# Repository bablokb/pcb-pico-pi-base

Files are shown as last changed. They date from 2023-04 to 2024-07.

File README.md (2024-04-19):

pcb-pico-pi-base
================

This projects provides two adapter-boards to run Pi-hats with a Pico.

The "pico-zero-base":

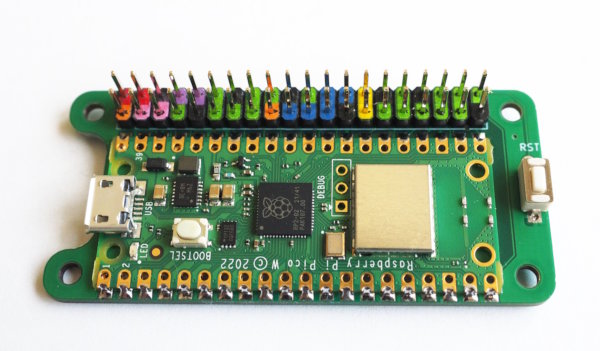
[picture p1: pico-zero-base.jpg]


and the "pico-pi-base":

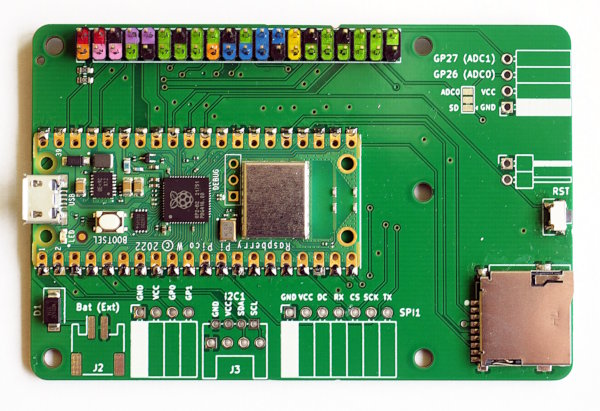
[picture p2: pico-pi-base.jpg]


The boards support (besides digital IO) I2C, I2S and SPI.

Supported Hats
--------------

The following hats were successfully tested:

  - Scroll pHat HD
  - Touch pHat
  - 4-Letter pHat
  - LED-Shim
  - Button-Shim
  - Pirate-Audio Speaker-Hat
  - Pirate-Audio Shim
  - Adafruit Speaker Bonnet
  - Display-Otron-Hat
  - InkyImpression  5.7"
  - Inky wHAT (black and white version)
  - Waveshare 4 inch RPi LCD (A)
  - I2C-Multiplexer-pHat

See the [examples page](examples/Readme.md) for details.

Hardware
--------

KiCad design-files are in `pico-zero-base.kicad` and in `pico-pi-base.kicad`
respectively. Ready to upload production files for JLCPCB are in `production_files`.

Except for I2C-pullups (and VSYS-diode on pico-pi-base) the adapter-boards
only map the pins of the Pico to pins of the Pi. The current versions
support I2C, SPI0, SPI1, I2S.

Schematic, layout and 3D-rendered images for pico-zero-base:

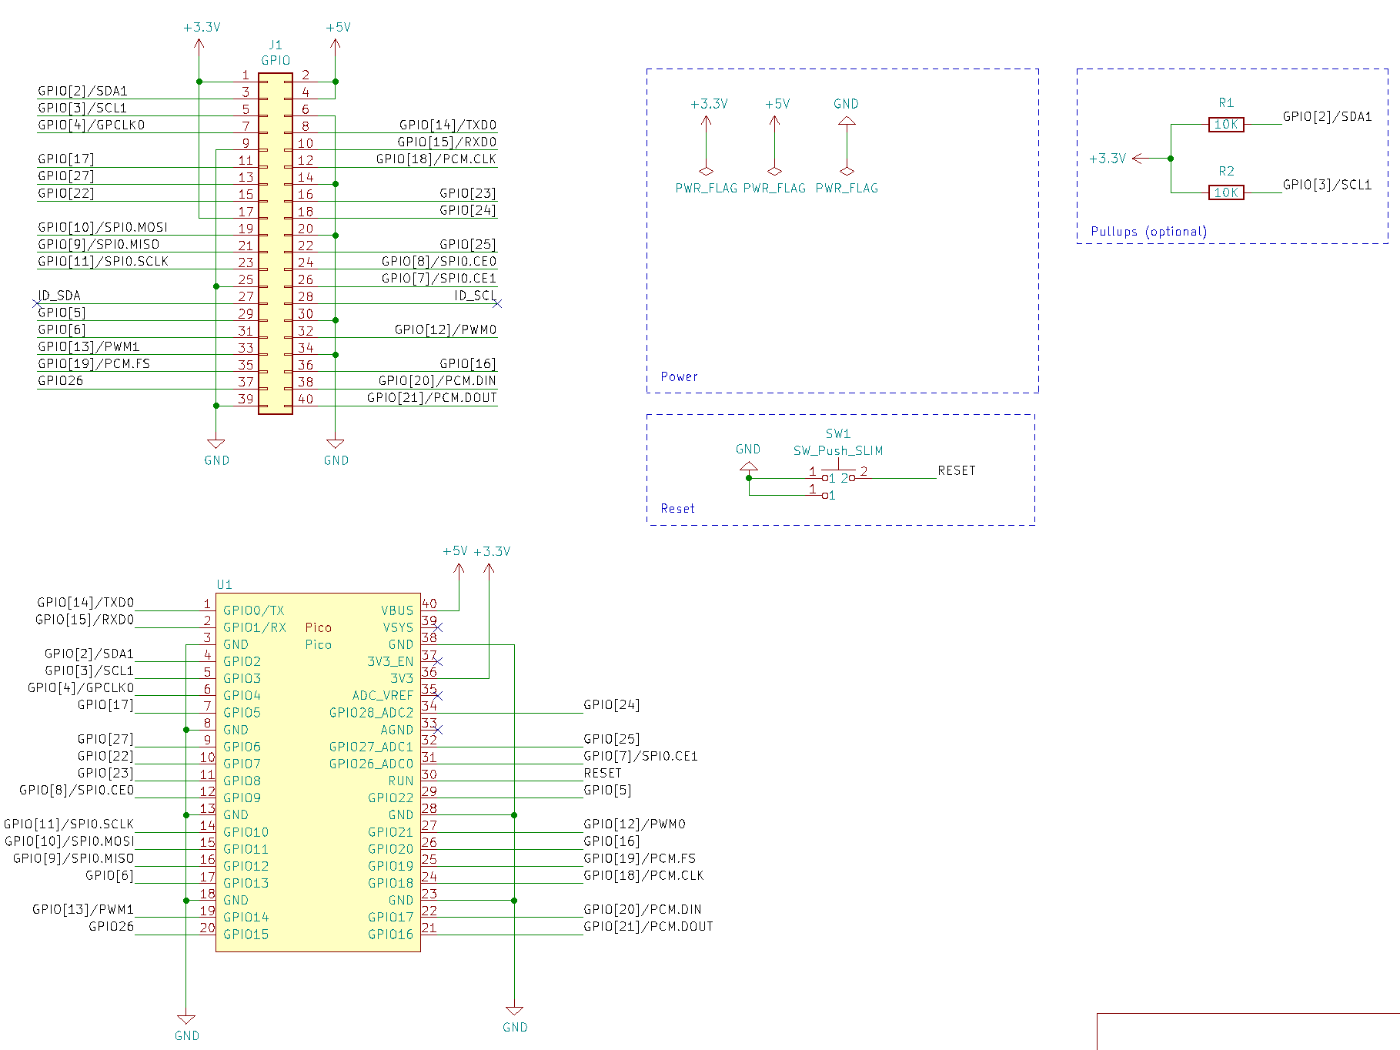
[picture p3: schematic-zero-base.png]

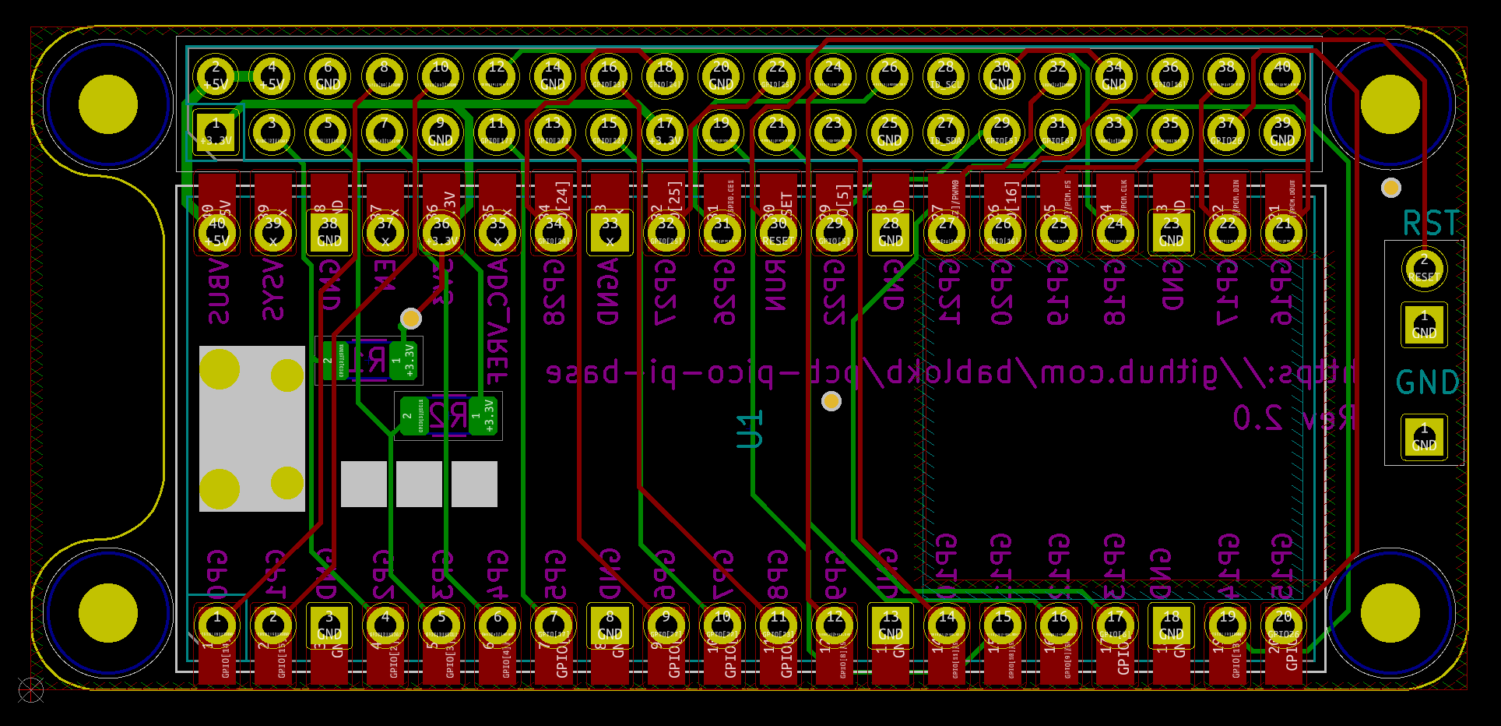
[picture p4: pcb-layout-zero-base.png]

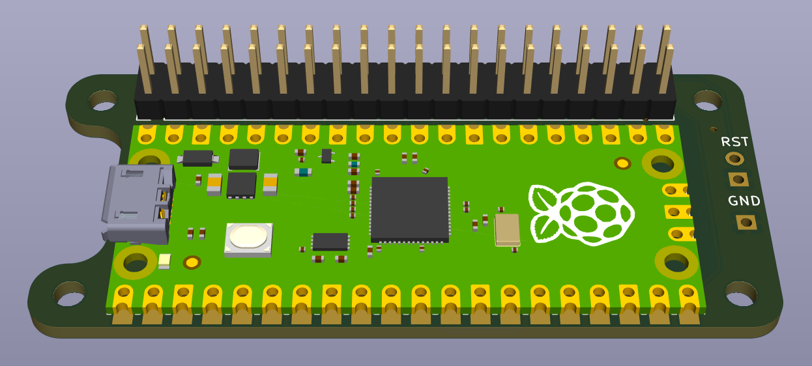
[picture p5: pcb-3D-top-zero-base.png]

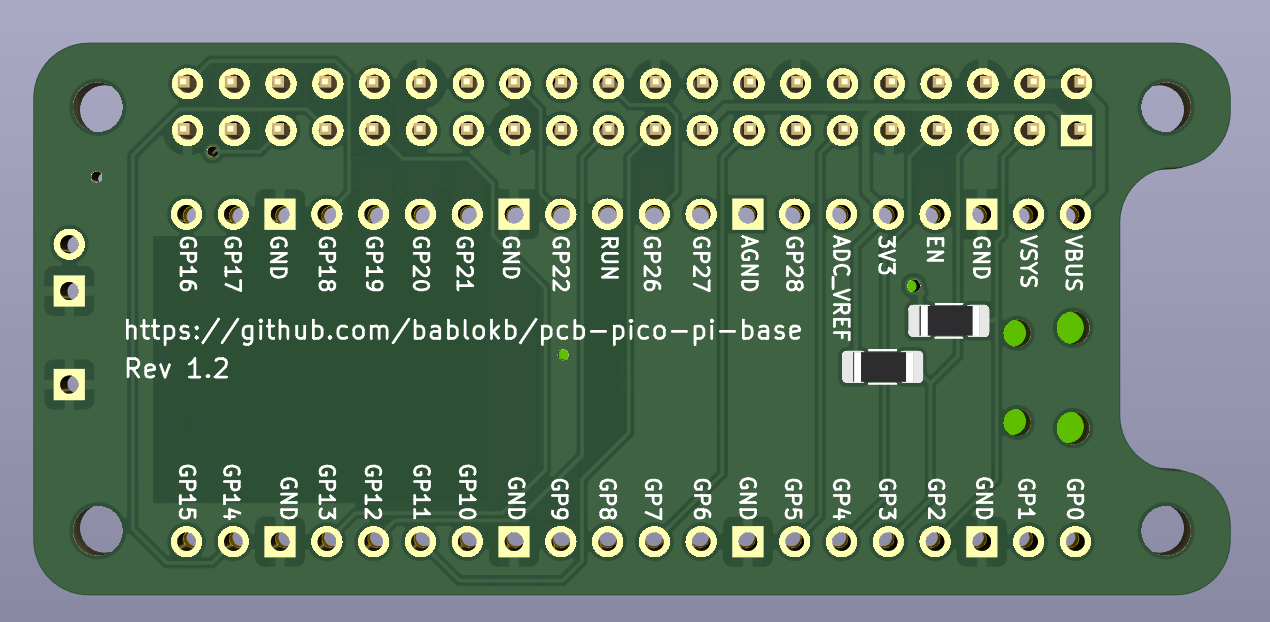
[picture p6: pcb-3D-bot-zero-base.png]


Schematic, layout and 3D-rendered images for pico-pi-base:

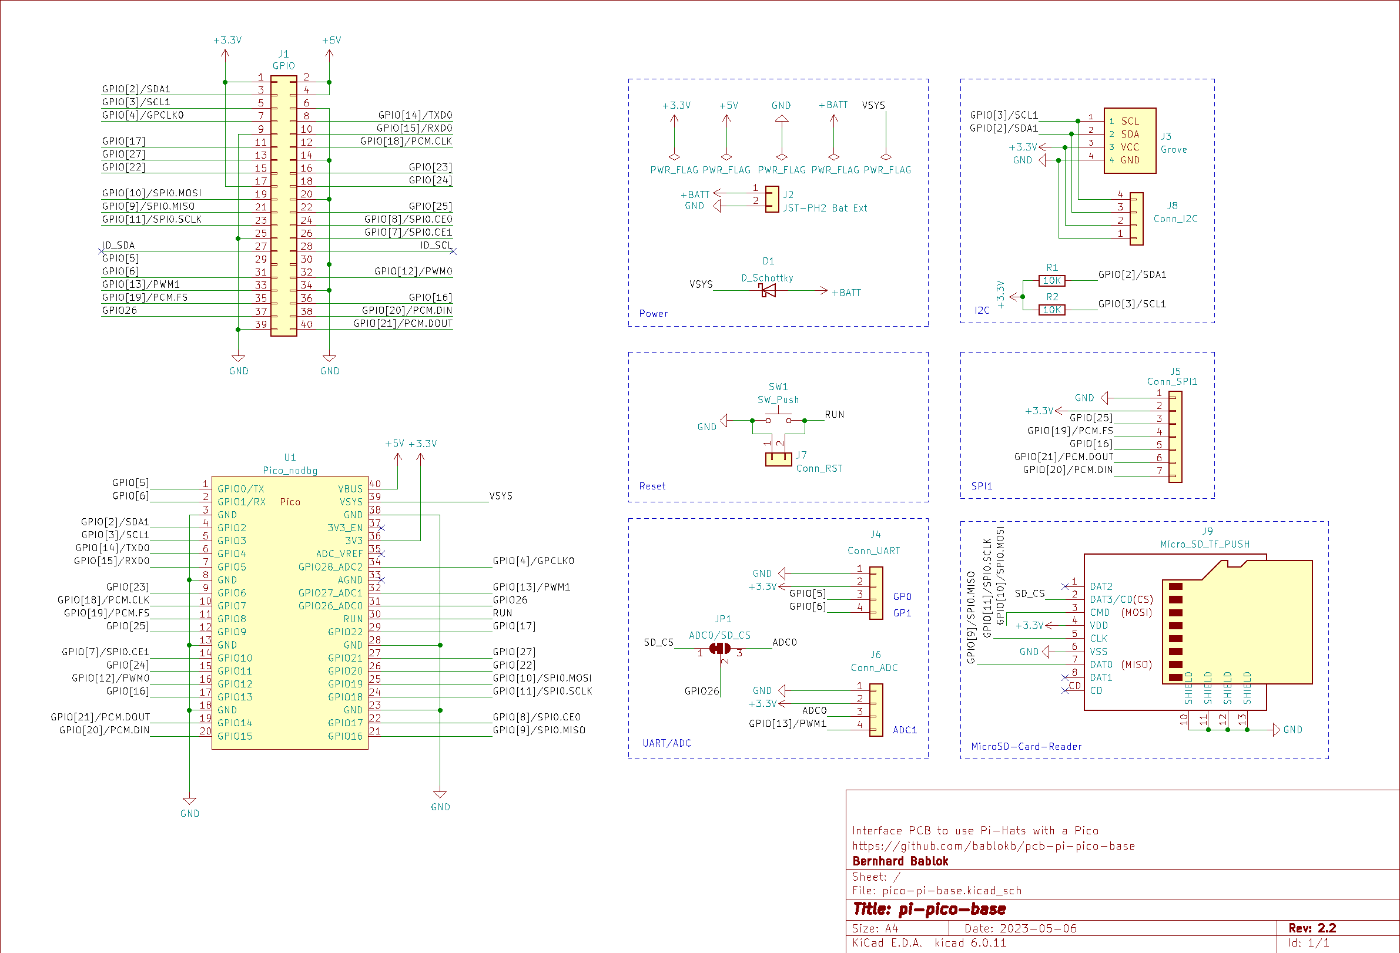
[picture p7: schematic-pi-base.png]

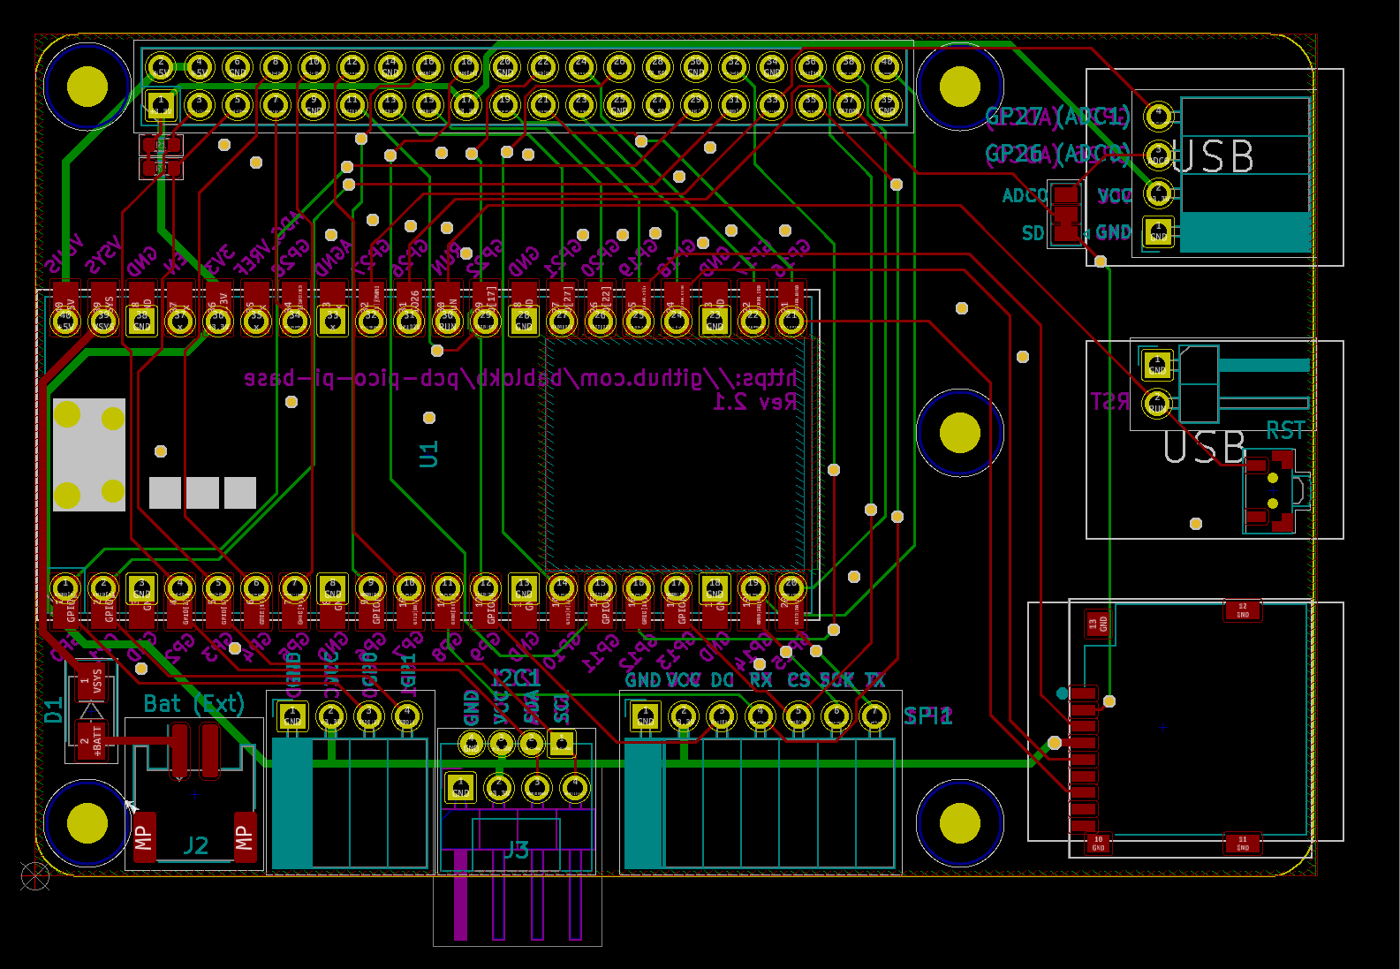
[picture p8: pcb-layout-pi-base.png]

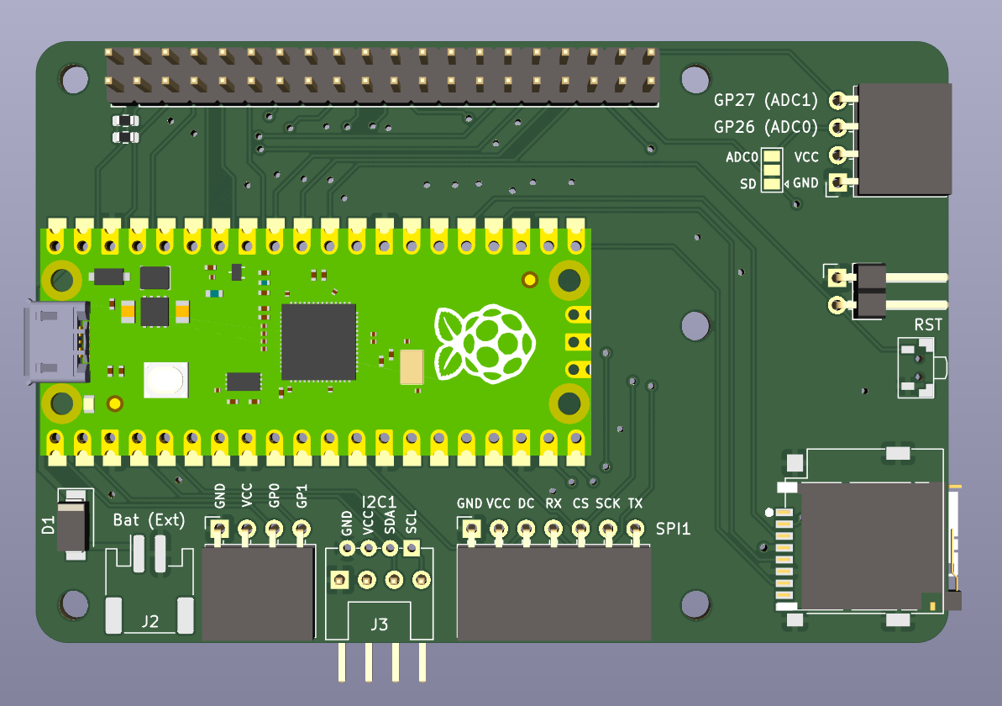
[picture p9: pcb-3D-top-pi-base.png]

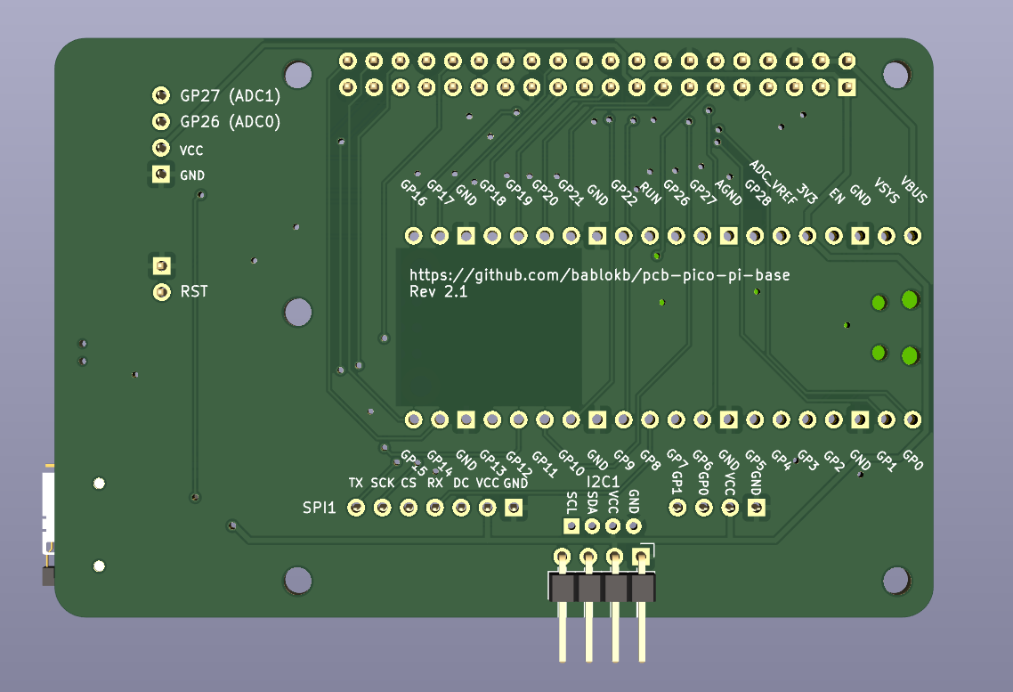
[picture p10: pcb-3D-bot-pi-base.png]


Software
--------

Since you cannot run Linux-software on the Pico, you need to check if there is a
Pico-driver available for your hats or adapt existing Pi drivers to the Pico. Since
many hats have python-drivers, this is not too difficult. Most hats only use
I2C and/or SPI anyhow.

In the directory `lib` you will find CircuitPython drivers for the supported
hats, unless there is a ready to use driver available.

The directory `examples` contains example programs.

The software currently assumes that you use special CircuitPython-builds
that do the pin mapping (see the directory `circuitpython`).
If not, you have to manually look up the [mapping](mapping.ods).

Porting to MicroPython from CircuitPython should be very simple, since
CircuitPython is only a fork of MicroPython and all the drivers use only
I2C, SPI and digital-IO.

License
-------

[![CC BY-SA 4.0][cc-by-sa-shield]][cc-by-sa]

This work is licensed under a
[Creative Commons Attribution-ShareAlike 4.0 International
License][cc-by-sa].

[][cc-by-sa]

[cc-by-sa]: http://creativecommons.org/licenses/by-sa/4.0/
[cc-by-sa-image]: https://licensebuttons.net/l/by-sa/4.0/88x31.png
[cc-by-sa-shield]:
https://img.shields.io/badge/License-CC%20BY--SA%204.0-lightgrey.svg

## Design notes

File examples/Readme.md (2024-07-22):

Examples
========

Some example programs for various hats. Check the `lib`-directory for
necessary (CircuitPython) drivers.

All the drivers assume that the mapping is done by the board-module.
E.g. the driver uses `board.GPIO24` and this is then mapped automatically
to the correct `board.GPxx`.

Some more examples are available here (for similar boards):
<https://github.com/dglaude/circuitpython_phat_on_pico>

Blinkt!
-------

This is a row of 8 APA102-LEDs with a connector. Simple and easy for nice
visual effects. It does not use I2C, but bit-banging with clock on GPIO24
and data on GPIO23. Porting was easy, replacing RPi.GPIO with digitalio.

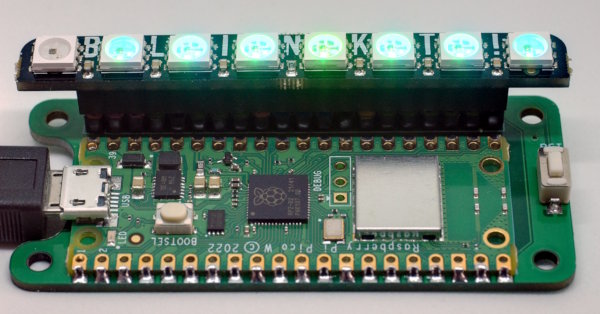
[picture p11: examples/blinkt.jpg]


Scroll pHat HD
--------------

Pimoroni's Scroll pHAT HD (now a retired product). Should also work
with the Scroll Hat Mini (<https://shop.pimoroni.com/products/scroll-hat-mini>).

A hat with 11x7 (monochrome) LEDs. The example is from
<http://github.com/adafruit/Adafruit_CircuitPython_IS31FL3731> and
uses the driver from that repo.

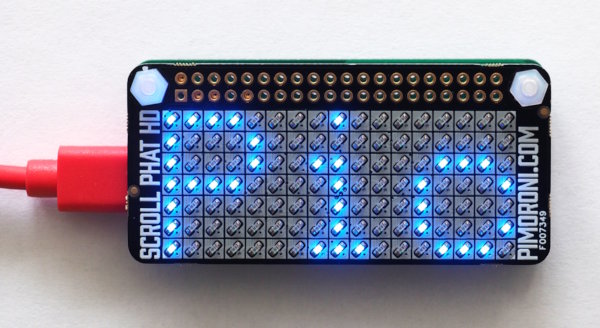
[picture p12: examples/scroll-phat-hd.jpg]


Touch pHat
----------

Pimoroni's Touch pHat <https://shop.pimoroni.com/products/touch-phat>.

The driver for the pHat and the CAP1166 chip were ported from the
Linux-version supplied by Pimoroni.

4-Letter pHat
-------------

A 4x14 segment display pHat <https://shop.pimoroni.com/products/four-letter-phat>.

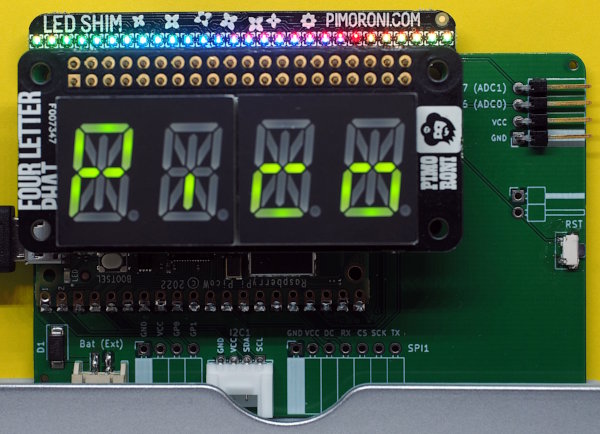
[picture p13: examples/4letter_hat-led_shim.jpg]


Works out of the box with <http://github.com/adafruit/Adafruit_CircuitPython_HT16K33>.

LED-Shim
--------

Also from Pimoroni <https://shop.pimoroni.com/products/led-shim>. You can see
it above the 4-letter pHat in the image above.

Same driver as the scroll pHat: <http://github.com/adafruit/Adafruit_CircuitPython_IS31FL3731>. The example is from that repo too.

Button-Shim
-----------

A small pcb with five buttons and a RGB-LED from Pimoroni:
<https://shop.pimoroni.com/products/button-shim>.

Pirate-Audio Speaker-Hat
------------------------

A hat from Pimoroni with a 240x240 display, four buttons, an audio DAC and
a small speaker (<https://shop.pimoroni.com/products/pirate-audio-mini-speaker>).

There are a few variants of this head available and all should work the same.

Rev1-boards only support the display and the buttons.
Rev2-boards also support audio.

All components are directly supported with standard CircuitPython drivers.

The hats have a major design flaw: they use the MISO-pin for the TFT-D/C,
so you cannot use SPI-devices together with this hat, at least as long as
you need MOSI. This really hurts, since this means you cannot read files
from the SD-card. And it is absolutely unnessary to use this pin, since
the Pi has so many other unused pins :-(

Audio DAC Shim
--------------

A solderless (more or less) shim with a 3.5mm line-out from Pimoroni
<https://shop.pimoroni.com/products/audio-dac-shim-line-out>.

Needs a Rev2-board. Audio-support for I2S is built into CircuitPython,
so no additional libs are necessary.

Adafruit Speaker-Bonnet
-----------------------

An audio hat with connectors for speakers, see
<https://www.adafruit.com/product/3346>.

This bonnet uses I2S and works without any additional libraries.
The example is from the guide
<https://learn.adafruit.com/adafruit-speaker-bonnet-for-raspberry-pi>. If you
compare the many pages of install instructions necessary to get this
working for a Pi you really love the simplicity of CircuitPython.

Adafruit LoRa-Bonnet
--------------------

A hat with a RFM9x-chip, three buttons and an I2C-OLED-display.
<https://www.adafruit.com/product/4074>.

The example is an adaption of the code in the guide
<https://learn.adafruit.com/multi-device-lora-temperature-network>.

Display-Otron-Hat
-----------------

From Pimoroni: <https://shop.pimoroni.com/products/display-o-tron-hat>.

The hat has a 3x16 character LCD with RGB backlight, six bar-graph
LEDs and six touch-buttons.

Fully supported, but the examples need some minor tweaks.

InkyImpression 4.0" and 5.7"
----------------------------

These 7-color e-ink displays are from Pimoroni:
<https://shop.pimoroni.com/products/inky-impression-5-7>

It is the same display as used in the InkyFrame 5.7", which has a Pico-W
attached. Main difference is that the latter also has a RTC and
some sophisticated power-management circuit.

The InkyImpression works out of the box with the SPD1656-driver from
Adafruit <http://github.com/adafruit/Adafruit_CircuitPython_SPD1656>.

Inky wHAT
---------

This is a 400x300 b&w e-ink display from Pimoroni (versions with an
additional color are also available, but are untested):
<https://shop.pimoroni.com/products/inky-what>

The driver is in `lib/what.py` and is a port of the (Linux-) Python-driver
from Pimoroni.

Inky pHAT
---------

This is a 250x122 b&w e-ink display from Pimoroni (versions with an
additional color are also available, but are untested):
<https://shop.pimoroni.com/products/inky-phat>

The driver is in `lib/phat.py` and is an adaption of the 
<https://github.com/adafruit/Adafruit_CircuitPython_SSD1608> driver
with input from the (Linux-) Python-driver of Pimoroni.

Waveshare 4-inch RPi LCD (A)
----------------------------

This is a 480x320 LCD-display with a 26-pin connector. It uses
the ILI4986-chip together with an XPT2046 for touch:
<https://www.waveshare.com/wiki/4inch_RPi_LCD_(A)>.

The display-driver needs a special hacked version of CircuitPython, the
patch is included in the directory `lib/ili9486_waveshare_4in`.

I2C-Multiplexer-pHat
--------------------

This 8-bus I2C-multiplexer pHat from independent maker 8086.net is based
on the TCA9548A and works with the TCA9548A-driver library from Adafruit
<https://github.com/adafruit/Adafruit_CircuitPython_TCA9548A>.

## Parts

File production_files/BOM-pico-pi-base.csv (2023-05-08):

Comment | Designator | Footprint | LCSC
D_Schottky | D1 | D_SMA | C2480
10K | R1,R2 | R_0603_1608Metric | C25804
Micro_SD_TF_PUSH | J9 | TF-Push | C393941

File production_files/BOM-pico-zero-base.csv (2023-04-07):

Comment | Designator | Footprint | LCSC
10K | R1,R2 | R_1206_3216Metric_Pad1.30x1.75mm_HandSolder | C17902

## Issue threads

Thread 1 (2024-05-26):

Not an issue: link to similar solution...

dglaude, 2024-05-26:
Hello,

Sorry not sure how to contact you... I found your article in Adafruit Playground.

When the Pico came out, I tried to find solution to reuse my HAT and pHAT collection on the pico... and use that with CircuitPython.

The best solution available at the time was Red Robotic Pico 2 Pi (that was available from Tindie): https://www.tomshardware.com/reviews/red-robotics-pico-2-pi-review-use-hats-with-raspberry-pi-pico ... maybe you can check this page to compare the mapping: https://www.hackster.io/news/the-pico-2-pi-adaptor-plate-proves-that-sometimes-it-s-the-simple-things-in-life-that-help-out-7f27e1de6208

I accumulated a few test in Circuit Python with various HAT: https://github.com/dglaude/circuitpython_phat_on_pico

I was in contact with the maker and helped make a new revision with SDA/SCL pull-up resistor. Indeed, your Raspberry Pi has that, and HAT / pHAT expect that, but on the Raspberry Pi Pico, because almost any pair of GPIO can be an I2C, there is none with the pull-up resistor.

At the time @arturo182 now owning Solder Party was working on a mapping and wanted to do a product that maybe never existed: https://www.hackster.io/news/the-zero-rp2040-is-an-rp2040-dev-board-that-tips-its-hat-to-the-former-zero-form-factor-8b71bf5a5deb

Now-a-day if someone want a PiZero like with with RP2040, I would suggest WaveShare RP2040-PiZero: https://www.waveshare.com/rp2040-pizero.htm ... I have two, I did not use them a lot, and especially not the unique aspect such as DVI/HDMI port or the USB Host (it require a OTG kind of cable).

Maybe you want to check those various attempt or product and compare your pin mapping or other technical decision they took.

Kind regards

David Glaude

bablokb, 2024-05-26:
Thanks for the links and infos. I indeed knew about the Robotic Pico 2 Pi hat, but it was neither available nor did I like the mappings. I will check your repo and if you like link from my examples page.

I also own the Waveshare board, but have not tested it. It is a very nice piece of engineering and the mapping seems ok except for I2S. The biggest drawback is the lack of WLAN. Another drawback is that many pins are used for other purposes and have added resistors, so you cannot just reuse them for your own purpose.

There is another adapter I recently discovered, available from The Pi Hut: https://thepihut.com/products/pico-to-pi-hat. Here also the mapping seems fine, but I also see no pullups.

dglaude, 2024-05-26:
Nice catch that PiHut version.

While writing my first message, I had in mind that I may have another I forgot to talk about... but that thing for pico to Pi mapping, I have "done it" (acquiring a few option) to map from Microbit (and especially the CLUE to Pi pinout) and also "done it" for Feather to Pi pinout too (also with one option from Arturo).

One thing I may have done is to import an alternate or overlay board.py that would map well know GPIO pin name to whatever is on the real board (like the pico). The goal was to have the example code work on different hardware without any modification.

One of the pin naming I wanted to have is the same that on CircuitPython running bare metal on Raspberry Pi Zero and/or on Blinka running on a Raspberry Pi (not sure if they are the same).

I think that the issue with WLAN is that it is kind of hard to have the Pico W chip and required licence outside of the Pico W... I don't think you can take a RP2040 and create a replica of the Pico W. So only adaptation board can have the Wifi and do that.

Anyway, good continuation with your project, I might get a copy, just like a might get the one from PiHut... just to have the whole collection. ;-)

bablokb, 2024-05-27:
I also tried to write a generic abstraction layer that makes the code work with all boards. It is too bad that you cannot monkey-patch board.py.

You can see my solution to the problem in the project https://github.com/bablokb/cp-departure-monitor. The hardware-abstraction-layer is loaded in `src/application.py`. This works with dynamic imports at runtime, loading a board-specific file and/or reading hardware-configuration from a settings-file. I am using this setup with all my (newer) projects and it works fine.

bablokb, 2024-06-03:
I added a link on the page `examples/Readme.md` to your repository.

Closed 2024-06-03.

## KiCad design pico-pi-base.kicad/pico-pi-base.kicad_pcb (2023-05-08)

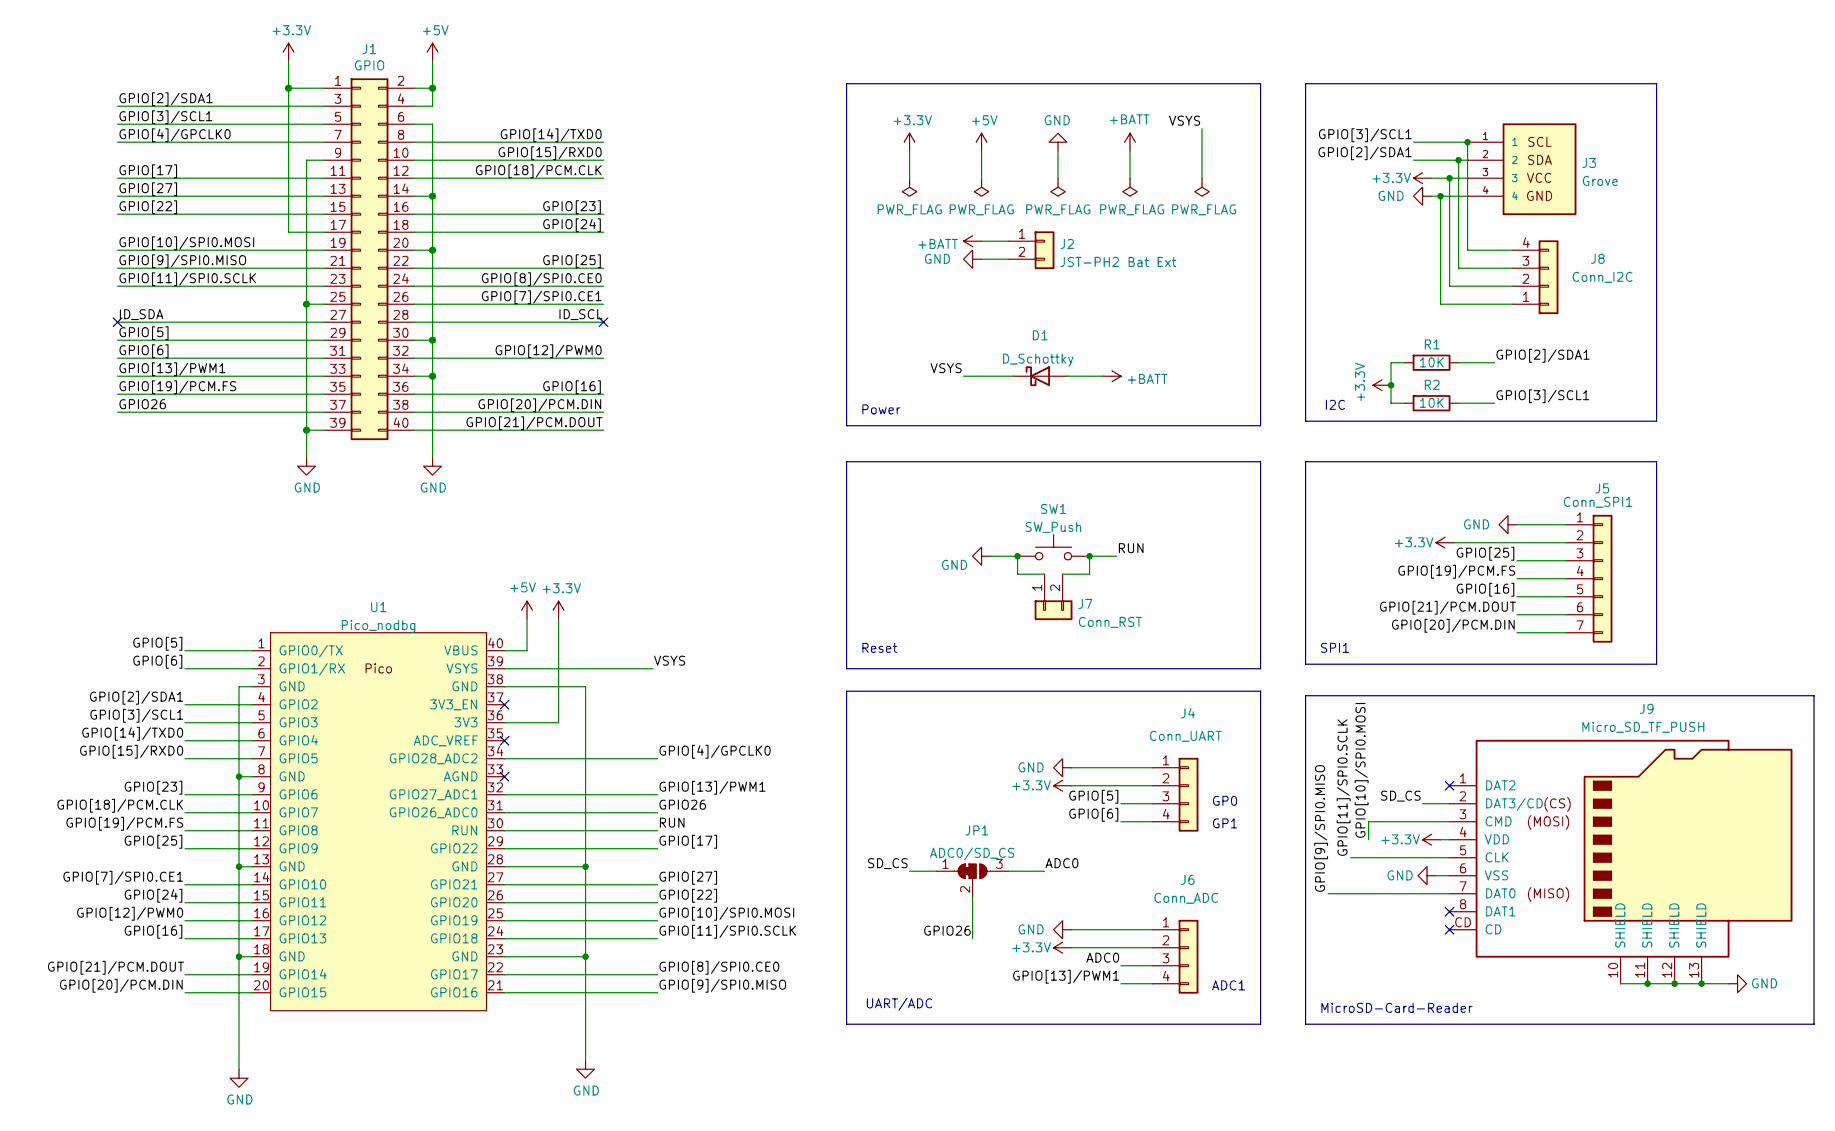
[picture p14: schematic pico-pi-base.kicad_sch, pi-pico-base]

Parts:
D1: D_Schottky; D_SMA; LCSC C2480
J1: GPIO; PinHeader_2x20_P2.54mm_Vertical
J2: JST-PH2 Bat Ext; JST_PH_S2B-PH-SM4-TB_1x02-1MP_P2.00mm_Horizontal
J3: Grove; grove_horizontal
J4: Conn_UART; PinSocket_1x04_P2.54mm_Horizontal
J5: Conn_SPI1; PinSocket_1x07_P2.54mm_Horizontal
J6: Conn_ADC; PinSocket_1x04_P2.54mm_Horizontal
J7: Conn_RST; PinHeader_1x02_P2.54mm_Horizontal
J8: Conn_I2C; PinHeader_1x04_P2.54mm_Horizontal
J9: Micro_SD_TF_PUSH; TF-Push; LCSC C393941
JP1: ADC0/SD_CS; SolderJumper-3_P1.3mm_Bridged12_Pad1.0x1.5mm
R1, R2: 10K; R_0603_1608Metric; LCSC C25804
SW1: SW_Push; Microtaster_Horizontal
U1: Pico_nodbg; RPi_Pico_SMD_TH_nodbg

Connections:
+3.3V: J1.1, J1.17, J3.3, J4.2, J5.2, J6.2, J8.2, J9.4 (VDD), R1.2, R2.2, U1.36 (3V3)
+5V: J1.2, J1.4, U1.40 (VBUS)
+BATT: D1.2 (A), J2.1
/ADC0: J6.3, JP1.3 (B)
/GPIO26: J1.37, JP1.2 (C), U1.31 (GPIO26_ADC0)
/GPIO[2]/SDA1: J1.3, J3.2, J8.3, R1.1, U1.4 (GPIO2)
/GPIO[3]/SCL1: J1.5, J3.1, J8.4, R2.1, U1.5 (GPIO3)
/GPIO[4]/GPCLK0: J1.7, U1.34 (GPIO28_ADC2)
/GPIO[5]: J1.29, J4.3, U1.1 (GPIO0/TX)
/GPIO[6]: J1.31, J4.4, U1.2 (GPIO1/RX)
/GPIO[7]/SPI0.CE1: J1.26, U1.14 (GPIO10)
/GPIO[8]/SPI0.CE0: J1.24, U1.22 (GPIO17)
/GPIO[9]/SPI0.MISO: J1.21, J9.7 (DAT0), U1.21 (GPIO16)
/GPIO[10]/SPI0.MOSI: J1.19, J9.3 (CMD), U1.25 (GPIO19)
/GPIO[11]/SPI0.SCLK: J1.23, J9.5 (CLK), U1.24 (GPIO18)
/GPIO[12]/PWM0: J1.32, U1.16 (GPIO12)
/GPIO[13]/PWM1: J1.33, J6.4, U1.32 (GPIO27_ADC1)
/GPIO[14]/TXD0: J1.8, U1.6 (GPIO4)
/GPIO[15]/RXD0: J1.10, U1.7 (GPIO5)
/GPIO[16]: J1.36, J5.5, U1.17 (GPIO13)
/GPIO[17]: J1.11, U1.29 (GPIO22)
/GPIO[18]/PCM.CLK: J1.12, U1.10 (GPIO7)
/GPIO[19]/PCM.FS: J1.35, J5.4, U1.11 (GPIO8)
/GPIO[20]/PCM.DIN: J1.38, J5.7, U1.20 (GPIO15)
/GPIO[21]/PCM.DOUT: J1.40, J5.6, U1.19 (GPIO14)
/GPIO[22]: J1.15, U1.26 (GPIO20)
/GPIO[23]: J1.16, U1.9 (GPIO6)
/GPIO[24]: J1.18, U1.15 (GPIO11)
/GPIO[25]: J1.22, J5.3, U1.12 (GPIO9)
/GPIO[27]: J1.13, U1.27 (GPIO21)
/ID_SCL: J1.28
/ID_SDA: J1.27
/RUN: J7.2, SW1.2, U1.30 (RUN)
/SD_CS: J9.2 (DAT3/CD), JP1.1 (A)
/VSYS: D1.1 (K), U1.39 (VSYS)
GND: J1.6, J1.9, J1.14, J1.20, J1.25, J1.30, J1.34, J1.39, J2.2, J3.4, J4.1, J5.1, J6.1, J7.1, J8.1, J9.6 (VSS), J9.10 (SHIELD), J9.11 (SHIELD), J9.12 (SHIELD), J9.13 (SHIELD), SW1.1, U1.3 (GND), U1.8 (GND), U1.13 (GND), U1.18 (GND), U1.23 (GND), U1.28 (GND), U1.38 (GND)

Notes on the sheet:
Reset
GP0
Power
GP1
MicroSD-Card-Reader
SPI1
UART/ADC
I2C
ADC1

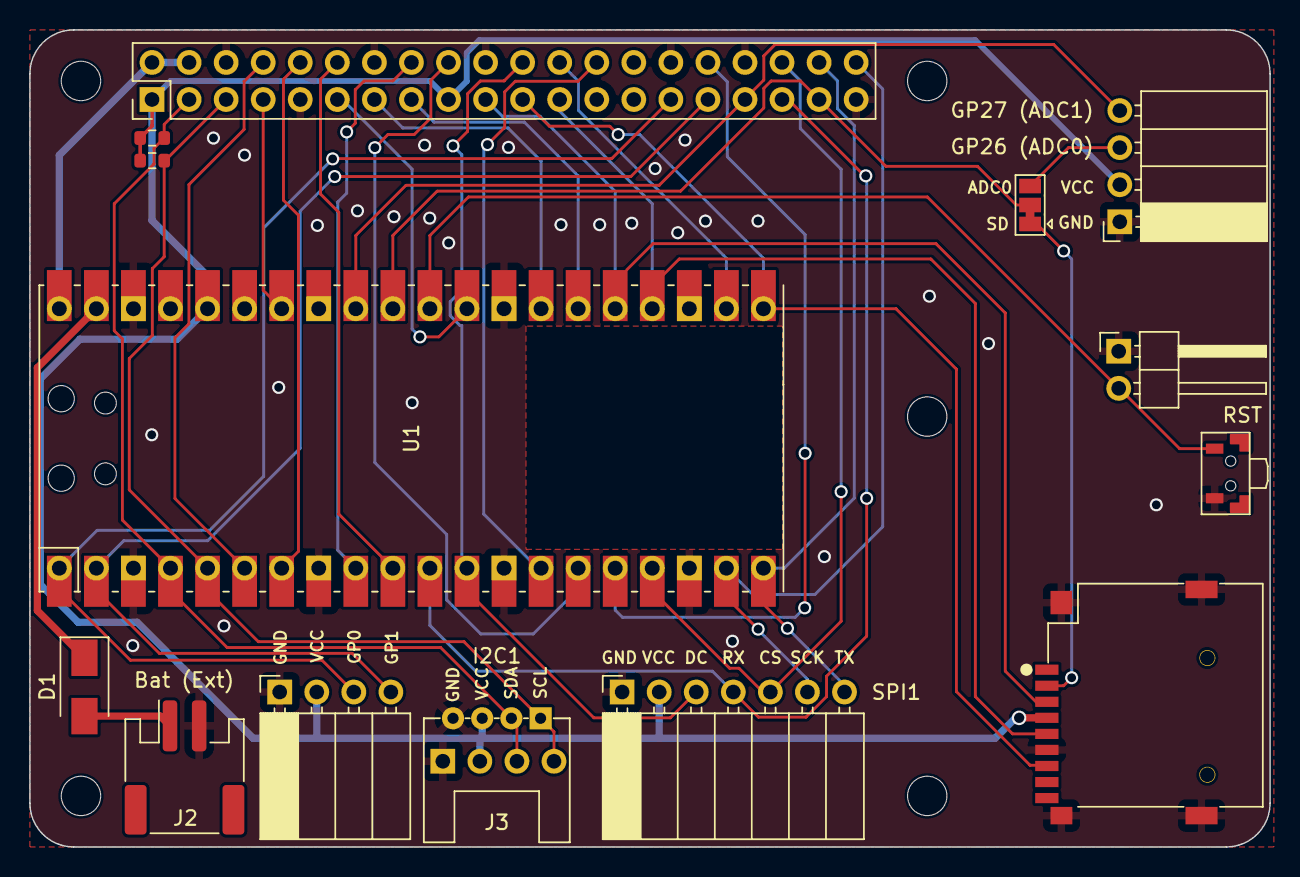
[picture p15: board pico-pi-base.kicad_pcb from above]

Board: 2 copper layers, 85.0 x 56.0 mm, 20 parts (1 on the bottom side), 34 nets.

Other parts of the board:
MH1, MH1#2, MH2, MH3, MH4: MountingHole_2.7mm_M2.5

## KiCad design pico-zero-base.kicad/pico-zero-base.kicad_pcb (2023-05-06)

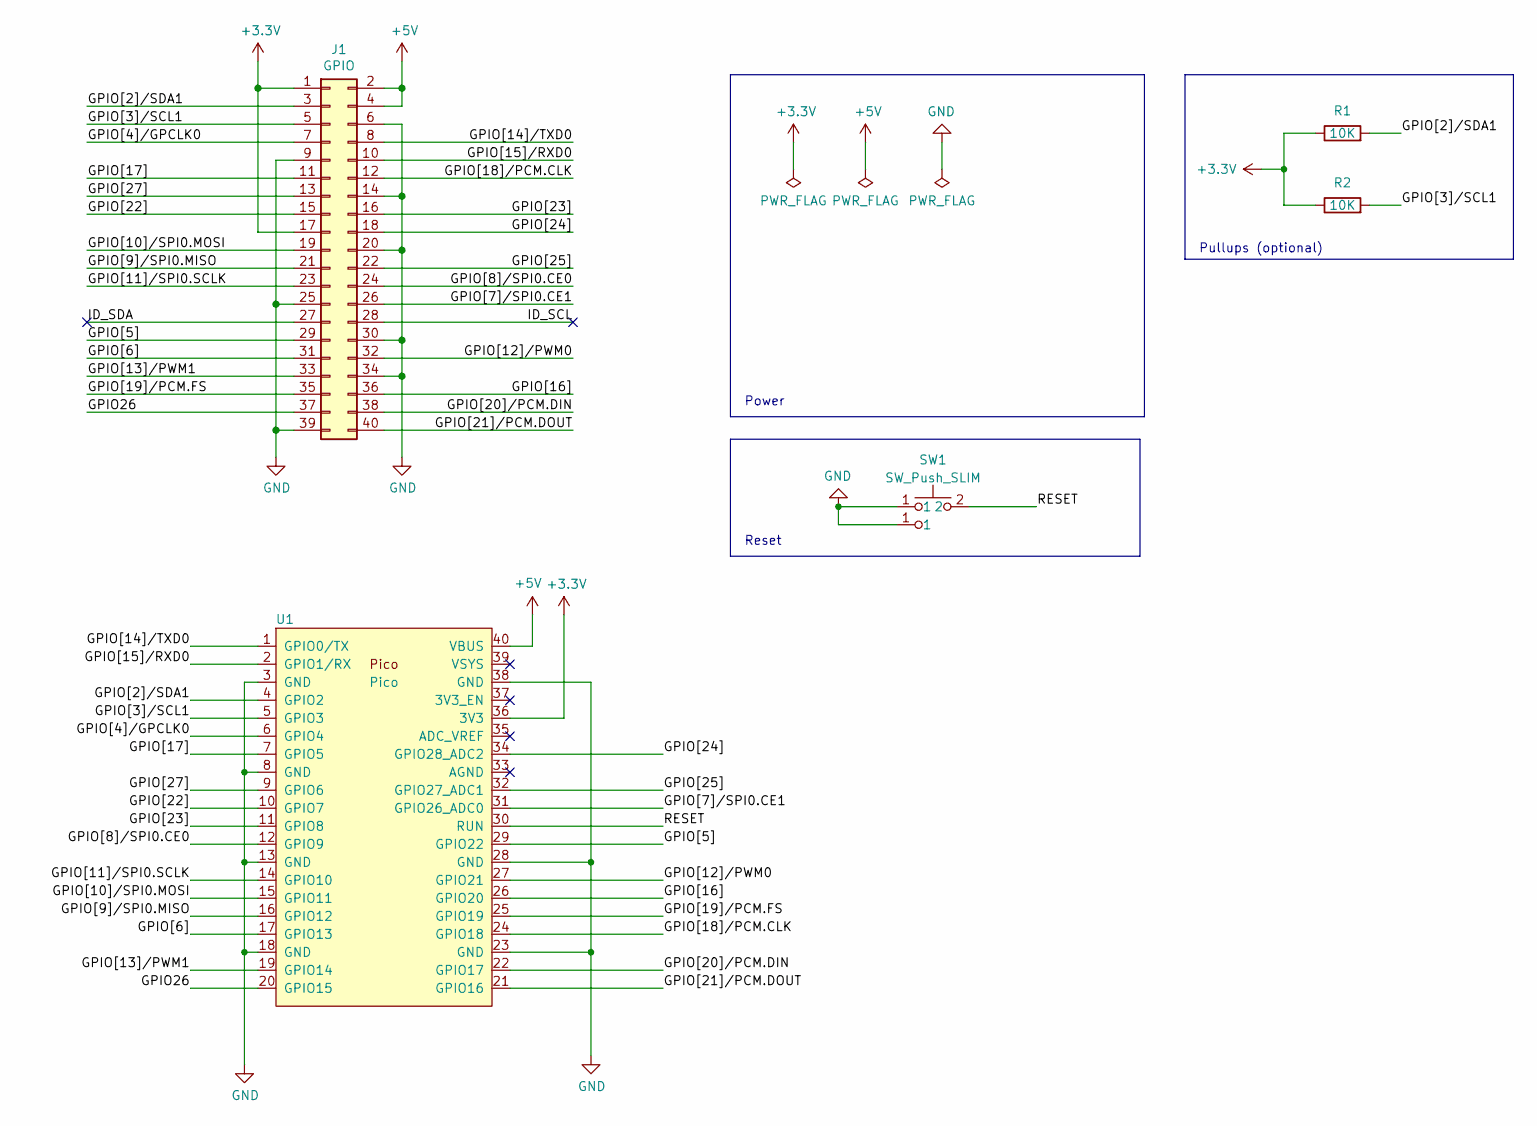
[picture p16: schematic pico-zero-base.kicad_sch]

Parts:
J1: GPIO; PinHeader_2x20_P2.54mm_Vertical
R1, R2: 10K; R_1206_3216Metric_Pad1.30x1.75mm_HandSolder; LCSC C17902
SW1: SW_Push_SLIM; SW_PUSH_SLIM_1x4
U1: Pico; RPi_Pico_SMD_TH_nodbg

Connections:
+3.3V: J1.1, J1.17, R1.1, R2.1, U1.36 (3V3)
+5V: J1.2, J1.4, U1.40 (VBUS)
/GPIO26: J1.37, U1.20 (GPIO15)
/GPIO[2]/SDA1: J1.3, R1.2, U1.4 (GPIO2)
/GPIO[3]/SCL1: J1.5, R2.2, U1.5 (GPIO3)
/GPIO[4]/GPCLK0: J1.7, U1.6 (GPIO4)
/GPIO[5]: J1.29, U1.29 (GPIO22)
/GPIO[6]: J1.31, U1.17 (GPIO13)
/GPIO[7]/SPI0.CE1: J1.26, U1.31 (GPIO26_ADC0)
/GPIO[8]/SPI0.CE0: J1.24, U1.12 (GPIO9)
/GPIO[9]/SPI0.MISO: J1.21, U1.16 (GPIO12)
/GPIO[10]/SPI0.MOSI: J1.19, U1.15 (GPIO11)
/GPIO[11]/SPI0.SCLK: J1.23, U1.14 (GPIO10)
/GPIO[12]/PWM0: J1.32, U1.27 (GPIO21)
/GPIO[13]/PWM1: J1.33, U1.19 (GPIO14)
/GPIO[14]/TXD0: J1.8, U1.1 (GPIO0/TX)
/GPIO[15]/RXD0: J1.10, U1.2 (GPIO1/RX)
/GPIO[16]: J1.36, U1.26 (GPIO20)
/GPIO[17]: J1.11, U1.7 (GPIO5)
/GPIO[18]/PCM.CLK: J1.12, U1.24 (GPIO18)
/GPIO[19]/PCM.FS: J1.35, U1.25 (GPIO19)
/GPIO[20]/PCM.DIN: J1.38, U1.22 (GPIO17)
/GPIO[21]/PCM.DOUT: J1.40, U1.21 (GPIO16)
/GPIO[22]: J1.15, U1.10 (GPIO7)
/GPIO[23]: J1.16, U1.11 (GPIO8)
/GPIO[24]: J1.18, U1.34 (GPIO28_ADC2)
/GPIO[25]: J1.22, U1.32 (GPIO27_ADC1)
/GPIO[27]: J1.13, U1.9 (GPIO6)
/ID_SCL: J1.28
/ID_SDA: J1.27
/RESET: SW1.2, U1.30 (RUN)
GND: J1.6, J1.9, J1.14, J1.20, J1.25, J1.30, J1.34, J1.39, SW1.1, U1.3 (GND), U1.8 (GND), U1.13 (GND), U1.18 (GND), U1.23 (GND), U1.28 (GND), U1.38 (GND)

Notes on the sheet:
Pullups (optional)
Power
Reset

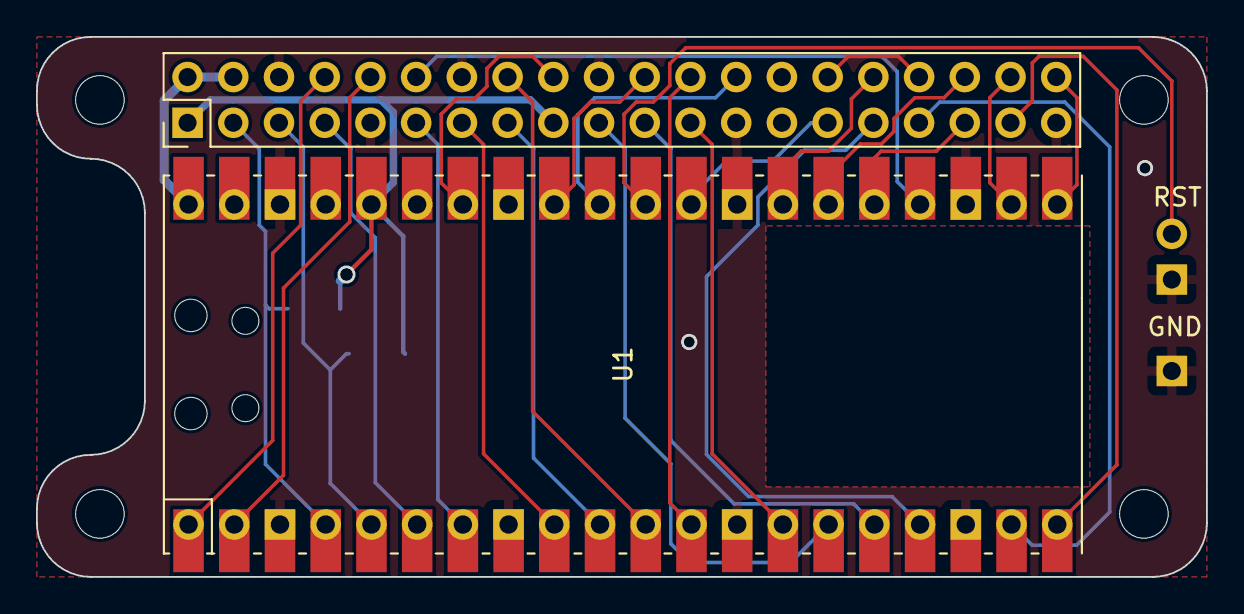
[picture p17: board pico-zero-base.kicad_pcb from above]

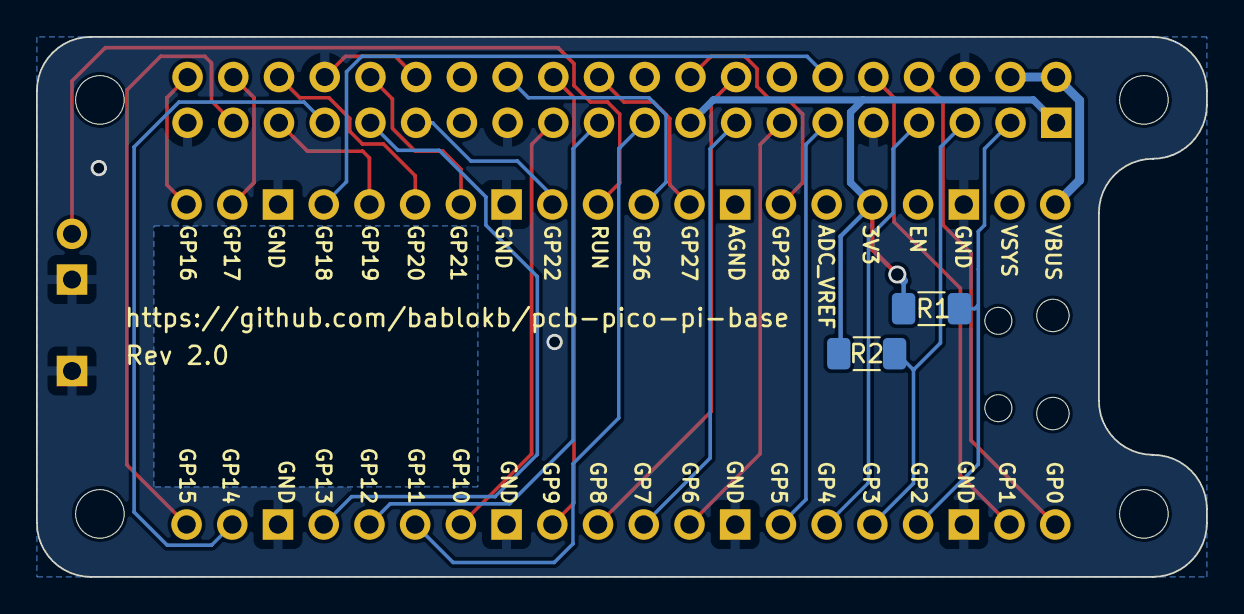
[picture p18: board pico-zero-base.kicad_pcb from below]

Board: 2 copper layers, 65.0 x 30.0 mm, 9 parts (2 on the bottom side), 30 nets.

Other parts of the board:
MH1, MH2, MH3, MH4: MountingHole_2.7mm_M2.5

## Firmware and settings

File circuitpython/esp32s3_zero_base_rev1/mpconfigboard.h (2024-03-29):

#define MICROPY_HW_BOARD_NAME "ESP32S3 Zero Base Rev1"
#define MICROPY_HW_MCU_NAME         "ESP32S3"

#define MICROPY_HW_NEOPIXEL         (&pin_GPIO21)

#define CIRCUITPY_BOARD_I2C         (1)
#define CIRCUITPY_BOARD_I2C_PIN     {{.scl = &pin_GPIO14, .sda = &pin_GPIO13}}

#define DEFAULT_SPI_BUS_SCK         (&pin_GPIO35)
#define DEFAULT_SPI_BUS_MISO        (&pin_GPIO37)
#define DEFAULT_SPI_BUS_MOSI        (&pin_GPIO36)

#define CIRCUITPY_BOARD_UART        (1)
#define CIRCUITPY_BOARD_UART_PIN    {{.tx = &pin_GPIO11, .rx = &pin_GPIO12}}

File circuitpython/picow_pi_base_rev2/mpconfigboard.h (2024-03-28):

#define MICROPY_HW_BOARD_NAME "PicoW Pi Base Rev2"
#define MICROPY_HW_MCU_NAME "rp2040"

#define CIRCUITPY_DIGITALIO_HAVE_INVALID_PULL (1)
#define CIRCUITPY_DIGITALIO_HAVE_INVALID_DRIVE_MODE (1)

#define MICROPY_HW_LED_STATUS   (&pin_CYW0)

#define CIRCUITPY_BOARD_I2C         (1)
#define CIRCUITPY_BOARD_I2C_PIN     {{.scl = &pin_GPIO3, .sda = &pin_GPIO2}}

#define DEFAULT_SPI_BUS_SCK         (&pin_GPIO18)
#define DEFAULT_SPI_BUS_MISO        (&pin_GPIO16)
#define DEFAULT_SPI_BUS_MOSI        (&pin_GPIO19)

#define CIRCUITPY_BOARD_UART        (1)
#define CIRCUITPY_BOARD_UART_PIN    {{.tx = &pin_GPIO4, .rx = &pin_GPIO5}}

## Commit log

2023-04-01 initial commit (Rev 1)
    [pico-pi-base.kicad_pcb, pico-pi-base.kicad_sch]
2023-04-06 Pico Zero Base Rev 1
    [pico-zero-base.kicad_pcb, pico-zero-base.kicad_sch]
2023-04-06 Added reset-button
    [pico-zero-base.kicad_pcb, pico-zero-base.kicad_sch]
2023-04-06 use pin-header instead of socket Rev 1.1
    [pico-zero-base.kicad_pcb, pico-zero-base.kicad_sch]
2023-04-06 increase 3V3 trace width to 0.4
    [pico-zero-base.kicad_pcb]
2023-04-07 add optional pullups Rev 1.2
    [BOM-pico-zero-base.csv, pico-zero-base.kicad_pcb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]
2023-04-11 pico-pi-base Rev 1.2
    [BOM-pico-pi-base.csv, pico-pi-base.kicad_pcb, pico-pi-base.kicad_sch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]
2023-04-27 Rev 2.0: swapped pins to support I2S
    [mapping.ods, pico-pi-base.kicad_pcb, pico-pi-base.kicad_sch]
2023-04-28 Rev 2.1: add MicroSD-BFF
    [mapping.ods, pico-pi-base.kicad_pcb, pico-pi-base.kicad_sch]
2023-04-29 added 4-Letter-pHat and LED-Shim
2023-05-04 added driver and examples for Display-Otron-Hat
2023-05-04 removed note about I2S not available on pico-zero-base
2023-05-06 pico-zero-base: Rev 2.0
    [pico-zero-base.kicad_pcb, pico-zero-base.kicad_sch]
2023-05-06 don't use board.SPI()
2023-05-08 pico-pi-base: Rev. 2.2
    [BOM-pico-pi-base.csv, pico-pi-base.kicad_pcb, pico-pi-base.kicad_sch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]
2023-05-18 document rev1+rev2 pinouts
    [mapping.ods]
2023-05-19 support Button-Shim
2023-05-19 CircuitPython board-definitions for pico-zero-base rev2 (for Pico)
2023-05-27 CircuitPython board-definitions for pico-pi-base-w rev2 (for Pico-W)
2023-07-05 added example for I2C-Multiplexer pHat from 8086.net
2023-07-17 added pinout for Adafruit-RFM9x-radio-bonnet
    [mapping.ods]
2023-09-18 added support for pico-zero-base-w Rev2
2024-02-13 fixed info about I2S
    [mapping.ods]
2024-03-28 changed board name for consistency
2024-03-28 add support for Waveshare ESP32S3-Pico
2024-03-28 updated mapping info for zero
    [mapping.ods]
2024-03-29 added board-files for ESP32S3 on zero-base-rev1
2024-07-22 hardcode width/height in driver
